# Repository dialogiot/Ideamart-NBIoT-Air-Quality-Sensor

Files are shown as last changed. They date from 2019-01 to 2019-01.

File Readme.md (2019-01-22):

##  Ideamart NB-IoT Air Quality Sensor

The board is developed based on the SIM7000C and SIM7000E Modules as well as the Microcontroller ATMega 328 based on the most popular Arduino UNO PIN layout. Therefore this board is compatible with any shield that is compatible with the Arduino UNO

* Temperature(Celsius)
* Carbon Dioxide(ppm)
* Pressure(Pa)
* Humidity(%)
* Ammonia(ppm)
* Butane(ppm)
* Carbon Monoxide(ppm)
* Ethanol(ppm)
* Hydrogen(ppm)
* Methane(ppm)
* Nitrogen Dioxide(ppm)
* Propane(ppm)
* Latitude, Longitude
* Altitude(m)
* MSL Altitude(m)
* Speed Over Ground(km/h)
* Course Over Ground(degrees)
* RSSI
* Battery Level(%)
* UTC date & Time
* Volatile Organic Compound(ppb)

More  (https://idealab.ideamart.io/EnvSensor/)

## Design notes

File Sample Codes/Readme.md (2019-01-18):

Use these sample codes for caliberation and additional sensors

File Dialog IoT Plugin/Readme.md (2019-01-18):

The air quality sensor uses CSV to send data to the platform. Therefore, the user is required to use this Java Plugin to connect the device with Dialog's IoT platform.
This plugin archive should be uploaded when onboarding the device through Dialog IoT Developer portal

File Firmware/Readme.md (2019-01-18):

Firmware for Airquality measurements
Use Arduino IDE with libraries from https://github.com/dialogiot/Dialog-NB-IOT-Hackathon/tree/master/Libraries

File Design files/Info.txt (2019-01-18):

Schematics and PCB Design files in Autodesk Eagle

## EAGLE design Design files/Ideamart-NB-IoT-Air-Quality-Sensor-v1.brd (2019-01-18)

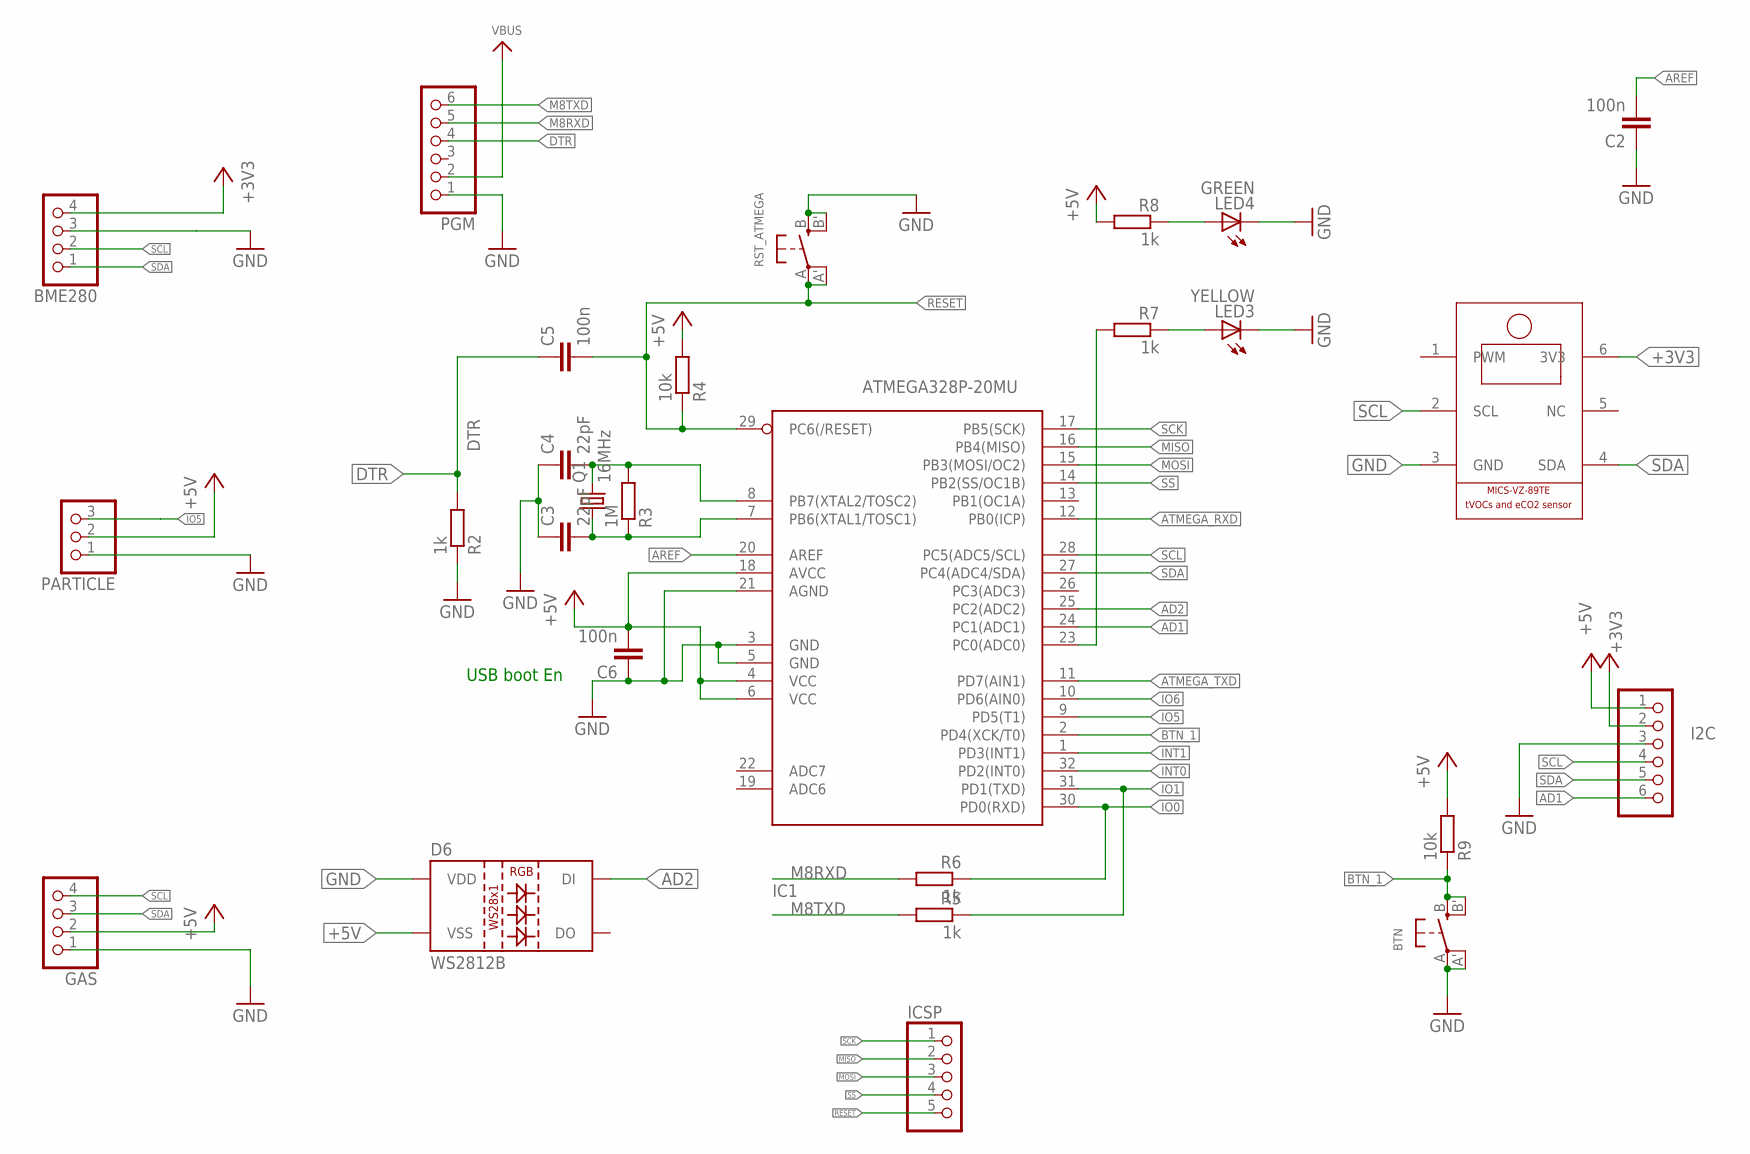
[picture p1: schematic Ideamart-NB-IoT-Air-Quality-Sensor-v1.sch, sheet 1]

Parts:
BME280: PINHD-1X4; 1X04
BTN: SWITCH_TACT_SMT4.6X2.8; BTN_KMR2_4.6X2.8
C2, C5, C6: 100n; C0805
C3, C4: 22pF; C0805
D6: WS2812B
GAS: PINHD-1X4; 1X04
I2C: PINHD-1X6; 1X06
IC1: ATMEGA328P-20MU; TQFP32-08
ICSP: PINHD-1X5; 1X05
LED3: YELLOW; CHIP-LED0805
LED4: GREEN; CHIP-LED0805
PARTICLE: PINHD-1X3; 1X03
PGM: PINHD-1X6; 1X06
Q1: 16MHz; CTS406
R2, R5, R6, R7, R8: 1k; R0805
R3: 1M; R0805
R4, R9: 10k; R0805
RST_ATMEGA: SWITCH_TACT_SMT4.6X2.8; BTN_KMR2_4.6X2.8
U$1: MICS-VZ-89TE

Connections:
+3V3: BME280.4, I2C.2, U$1.6 (3V3); also elsewhere on the board
+5V: C6.2, D6.3 (VSS), GAS.2, I2C.1, IC1.4 (VCC), IC1.6 (VCC), IC1.18 (AVCC), PARTICLE.2, R4.2, R8.2, R9.2; also elsewhere on the board
AD1: I2C.6, IC1.24 (PC1(ADC1))
AD2: D6.4 (DI), IC1.25 (PC2(ADC2))
AREF: C2.2, IC1.20 (AREF)
ATMEGA_RXD: IC1.12 (PB0(ICP)); also elsewhere on the board
ATMEGA_TXD: IC1.11 (PD7(AIN1)); also elsewhere on the board
BTN_1: BTN.B (S), BTN.B' (S1), IC1.2 (PD4(XCK/T0)), R9.1
DTR: C5.1, PGM.4, R2.2
GND: BME280.3, BTN.A, BTN.A' (P1), C2.1, C3.1, C4.1, C6.1, D6.1 (VDD), GAS.1, I2C.3, IC1.3 (GND), IC1.5 (GND), IC1.21 (AGND), LED3.C, LED4.C, PARTICLE.1, PGM.1, R2.1, RST_ATMEGA.B (S), RST_ATMEGA.B' (S1), U$1.3 (GND); also elsewhere on the board
INT0: IC1.32 (PD2(INT0))
INT1: IC1.1 (PD3(INT1))
IO0: IC1.30 (PD0(RXD)), R6.1
IO1: IC1.31 (PD1(TXD)), R5.1
IO5: IC1.9 (PD5(T1)), PARTICLE.3
IO6: IC1.10 (PD6(AIN0))
M8RXD: PGM.5, R6.2
M8TXD: PGM.6, R5.2
MISO: IC1.16 (PB4(MISO)), ICSP.2
MOSI: IC1.15 (PB3(MOSI/OC2)), ICSP.3; also elsewhere on the board
unnamed: LED3.A, R7.1
unnamed: LED4.A, R8.1
unnamed: IC1.23 (PC0(ADC0)), R7.2
RESET: C5.2, IC1.29 (PC6(/RESET)), ICSP.5, R4.1, RST_ATMEGA.A, RST_ATMEGA.A' (P1)
SCK: IC1.17 (PB5(SCK)), ICSP.1; also elsewhere on the board
SCL: BME280.2, GAS.4, I2C.4, IC1.28 (PC5(ADC5/SCL)), U$1.2 (SCL)
SDA: BME280.1, GAS.3, I2C.5, IC1.27 (PC4(ADC4/SDA)), U$1.4 (SDA)
SS: IC1.14 (PB2(SS/OC1B)), ICSP.4
VBUS: PGM.2; also elsewhere on the board
XTAL1: C3.2, IC1.7 (PB6(XTAL1/TOSC1)), Q1.1, R3.1
XTAL2: C4.2, IC1.8 (PB7(XTAL2/TOSC2)), Q1.3 (2), R3.2

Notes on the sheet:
USB boot En

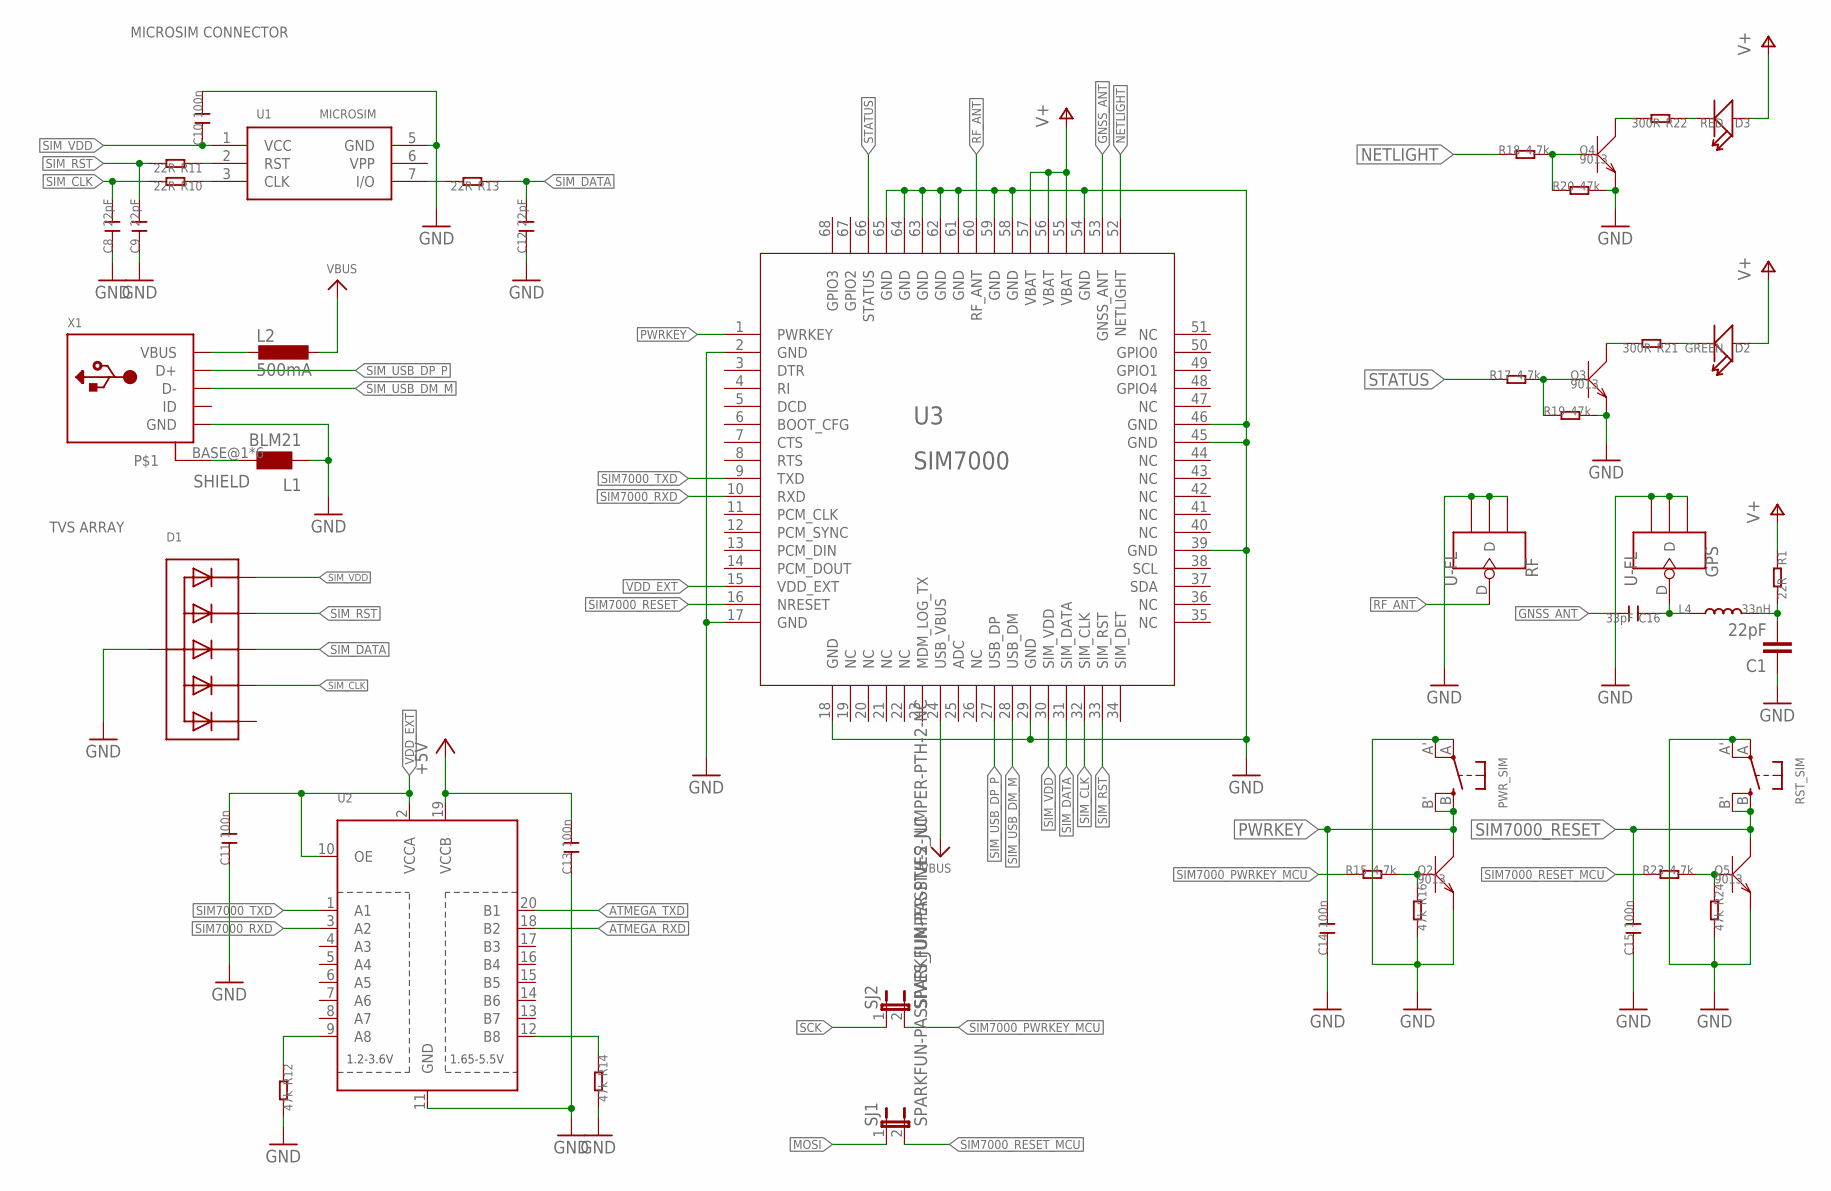
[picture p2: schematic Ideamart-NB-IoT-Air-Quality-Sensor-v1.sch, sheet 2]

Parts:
C1: 22pF; C0805
C8, C9, C12: 22pF; 0805
C10, C11, C13, C14, C15: 100n; 0805
C16: 33pF; 0805
D1: TVSARRAY_5LANE; SOT363
D2: GREEN; LED-0805
D3: RED; LED-0805
GPS: U-FL; 4P-U-FL
L1: BLM21; 0805
L2: 500mA; L1812
L4: 33nH; L0805
PWR_SIM: SWITCH_TACT_SMT4.6X2.8; BTN_KMR2_4.6X2.8
Q2, Q3, Q4, Q5: 9013; SOT23
R1, R10, R11, R13: 22R; 0805
R12, R14, R16, R19, R20, R24: 47k; 0805
R15, R17, R18, R23: 4.7k; 0805
R21, R22: 300R; 0805
RF: U-FL; 4P-U-FL
RST_SIM: SWITCH_TACT_SMT4.6X2.8; BTN_KMR2_4.6X2.8
SJ1, SJ2: SPARKFUN-PASSIVES_JUMPER-PTH-2-NC; SPARKFUN-PASSIVES_PTH-JUMPER-NC_BOTTOM_NO_SILK
U1: MICROSIM
U2: TXB0108PWR; TSSOP20
U3: SIM7000
X1: USB_MICRO_20329_V2; 4UCONN_20329_V2

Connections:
+5V: C13.2, U2.19 (VCCB); also elsewhere on the board
ATMEGA_RXD: U2.18 (B2); also elsewhere on the board
ATMEGA_TXD: U2.20 (B1); also elsewhere on the board
GND: C1.1, C8.1, C9.1, C10.2, C11.1, C12.1, C13.1, C14.1, C15.1, D1.2 (A), GPS.GND1, GPS.GND2, GPS.GND3, L1.1, PWR_SIM.A, PWR_SIM.A' (P1), Q2.2 (E), Q3.2 (E), Q4.2 (E), Q5.2 (E), R12.2, R14.2, R16.2, R19.2, R20.2, R24.2, RF.GND1, RF.GND2, RF.GND3, RST_SIM.A, RST_SIM.A' (P1), U1.5 (GND), U2.11 (GND), U3.2 (GND), U3.17 (GND), U3.18 (GND), U3.29 (GND), U3.39 (GND), U3.45 (GND), U3.46 (GND), U3.54 (GND), U3.58 (GND), U3.59 (GND), U3.61 (GND), U3.62 (GND), U3.63 (GND), U3.64 (GND), U3.65 (GND), X1.GND; also elsewhere on the board
GNSS_ANT: C16.2, U3.53 (GNSS_ANT)
GPIO2: U3.67 (GPIO2)
GPIO3: U3.68 (GPIO3)
MOSI: SJ1.1; also elsewhere on the board
unnamed: Q3.3 (C), R21.2
unnamed: D2.-, R21.1
unnamed: Q3.1 (B), R17.2, R19.1
unnamed: R13.2, U1.7 (I/O)
unnamed: R10.1, U1.3 (CLK)
unnamed: R11.1, U1.2 (RST)
unnamed: Q5.1 (B), R23.2, R24.1
unnamed: L2.2, X1.VBUS
unnamed: Q4.3 (C), R22.2
unnamed: D3.-, R22.1
unnamed: Q4.1 (B), R18.2, R20.1
unnamed: C16.1, GPS.D, L4.1
unnamed: R12.1, U2.9 (A8)
unnamed: R14.1, U2.12 (B8)
unnamed: C1.2, L4.2, R1.2
unnamed: Q2.1 (B), R15.2, R16.1
NETLIGHT: R18.1, U3.52 (NETLIGHT)
PWRKEY: C14.2, PWR_SIM.B (S), PWR_SIM.B' (S1), Q2.3 (C), U3.1 (PWRKEY)
RF_ANT: RF.D, U3.60 (RF_ANT)
SCK: SJ2.1; also elsewhere on the board
SHIELD: L1.2, X1.BASE@1, X1.BASE@2, X1.SPRT@1, X1.SPRT@2, X1.SPRT@3, X1.SPRT@4
SIM7000_PWRKEY_MCU: R15.1, SJ2.2
SIM7000_RESET: C15.2, Q5.3 (C), RST_SIM.B (S), RST_SIM.B' (S1), U3.16 (NRESET)
SIM7000_RESET_MCU: R23.1, SJ1.2
SIM7000_RXD: U2.3 (A2), U3.10 (RXD)
SIM7000_TXD: U2.1 (A1), U3.9 (TXD)
SIM_CLK: C8.2, D1.5 (C4), R10.2, U3.32 (SIM_CLK)
SIM_DATA: C12.2, D1.4 (C3), R13.1, U3.31 (SIM_DATA)
SIM_RST: C9.2, D1.3 (C2), R11.2, U3.33 (SIM_RST)
SIM_USB_DM_M: U3.28 (USB_DM), X1.D-
SIM_USB_DP_P: U3.27 (USB_DP), X1.D+
SIM_VDD: C10.1, D1.1 (C1), U1.1 (VCC), U3.30 (SIM_VDD)
STATUS: R17.1, U3.66 (STATUS)
V+: D2.+, D3.+, R1.1, U3.55 (VBAT), U3.56 (VBAT), U3.57 (VBAT); also elsewhere on the board
VBUS: L2.1, U3.24 (USB_VBUS); also elsewhere on the board
VDD_EXT: C11.2, U2.2 (VCCA), U2.10 (OE), U3.15 (VDD_EXT)

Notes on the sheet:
TVS ARRAY
MICROSIM CONNECTOR

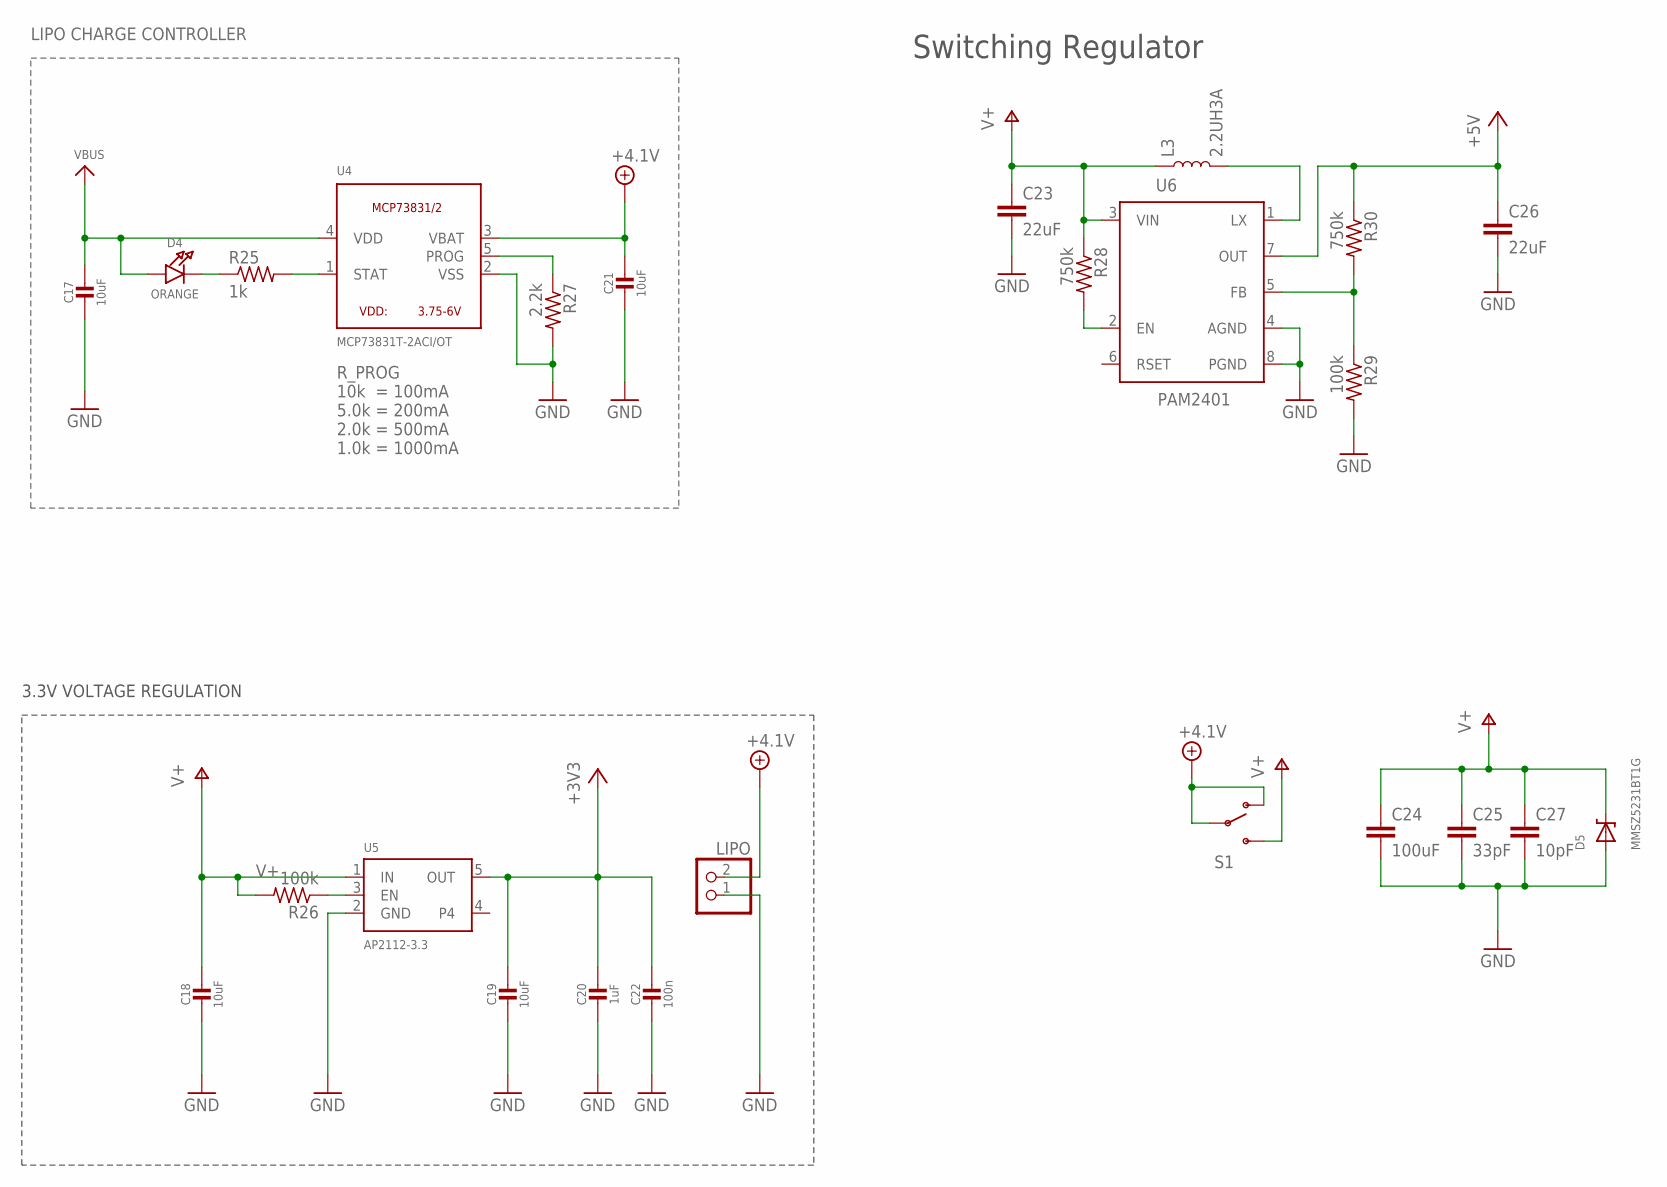
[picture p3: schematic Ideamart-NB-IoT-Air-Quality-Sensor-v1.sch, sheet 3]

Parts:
C17, C21: 10uF; _0805
C18, C19: 10uF; _0805MP
C20: 1uF; _0805MP
C22: 100n; _0805MP
C23, C26: 22uF; 0805
C24: 100uF; 1210
C25: 33pF; 0805
C27: 10pF; 0805
D4: ORANGE; CHIPLED_0805
D5: MMSZ5231BT1G; SOD-123
L3: 2.2UH3A; INDUCTOR_4X4MM
LIPO: JST_2PIN-SMT; JST-PH-2-SMT
R25: 1k; M0805
R26, R29: 100k; M0805
R27: 2.2k; M0805
R28, R30: 750k; M0805
S1: SWITCH-SPDT-SMD-A; SWITCH-SPST-SMD-A
U4: MCP73831T-2ACI/OT; SOT23-5
U5: AP2112-3.3; SOT23-5
U6: PAM2401; MSOP8

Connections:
+3V3: C19.1, C20.1, C22.1, U5.5 (OUT); also elsewhere on the board
+4.1V: C21.1, LIPO.2 (1), S1.1 (O), S1.2, U4.3 (VBAT)
+5V: C26.1, R30.1, U6.7 (OUT); also elsewhere on the board
EN: R28.2, U6.2 (EN)
GND: C17.2, C18.2, C19.2, C20.2, C21.2, C22.2, C23.2, C24.2, C25.2, C26.2, C27.2, D5.A, LIPO.1 (2), R27.2, R29.2, U4.2 (VSS), U5.2 (GND), U6.4 (AGND), U6.8 (PGND); also elsewhere on the board
unnamed: R26.1, U5.3 (EN)
unnamed: D4.C, R25.1
unnamed: R25.2, U4.1 (STAT)
unnamed: R27.1, U4.5 (PROG)
unnamed: R29.1, R30.2, U6.5 (FB)
unnamed: L3.P$2 (2), U6.1 (LX)
V+: C18.1, C23.1, C24.1, C25.1, C27.1, D5.C, L3.P$1 (1), R26.2, R28.1, S1.3 (S), U5.1 (IN), U6.3 (VIN); also elsewhere on the board
VBUS: C17.1, D4.A, U4.4 (VDD); also elsewhere on the board

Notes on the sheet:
3.3V VOLTAGE REGULATION
R_PROG 10k = 100mA 5.0k = 200mA 2.0k = 500mA 1.0k = 1000mA
LIPO CHARGE CONTROLLER
Switching Regulator

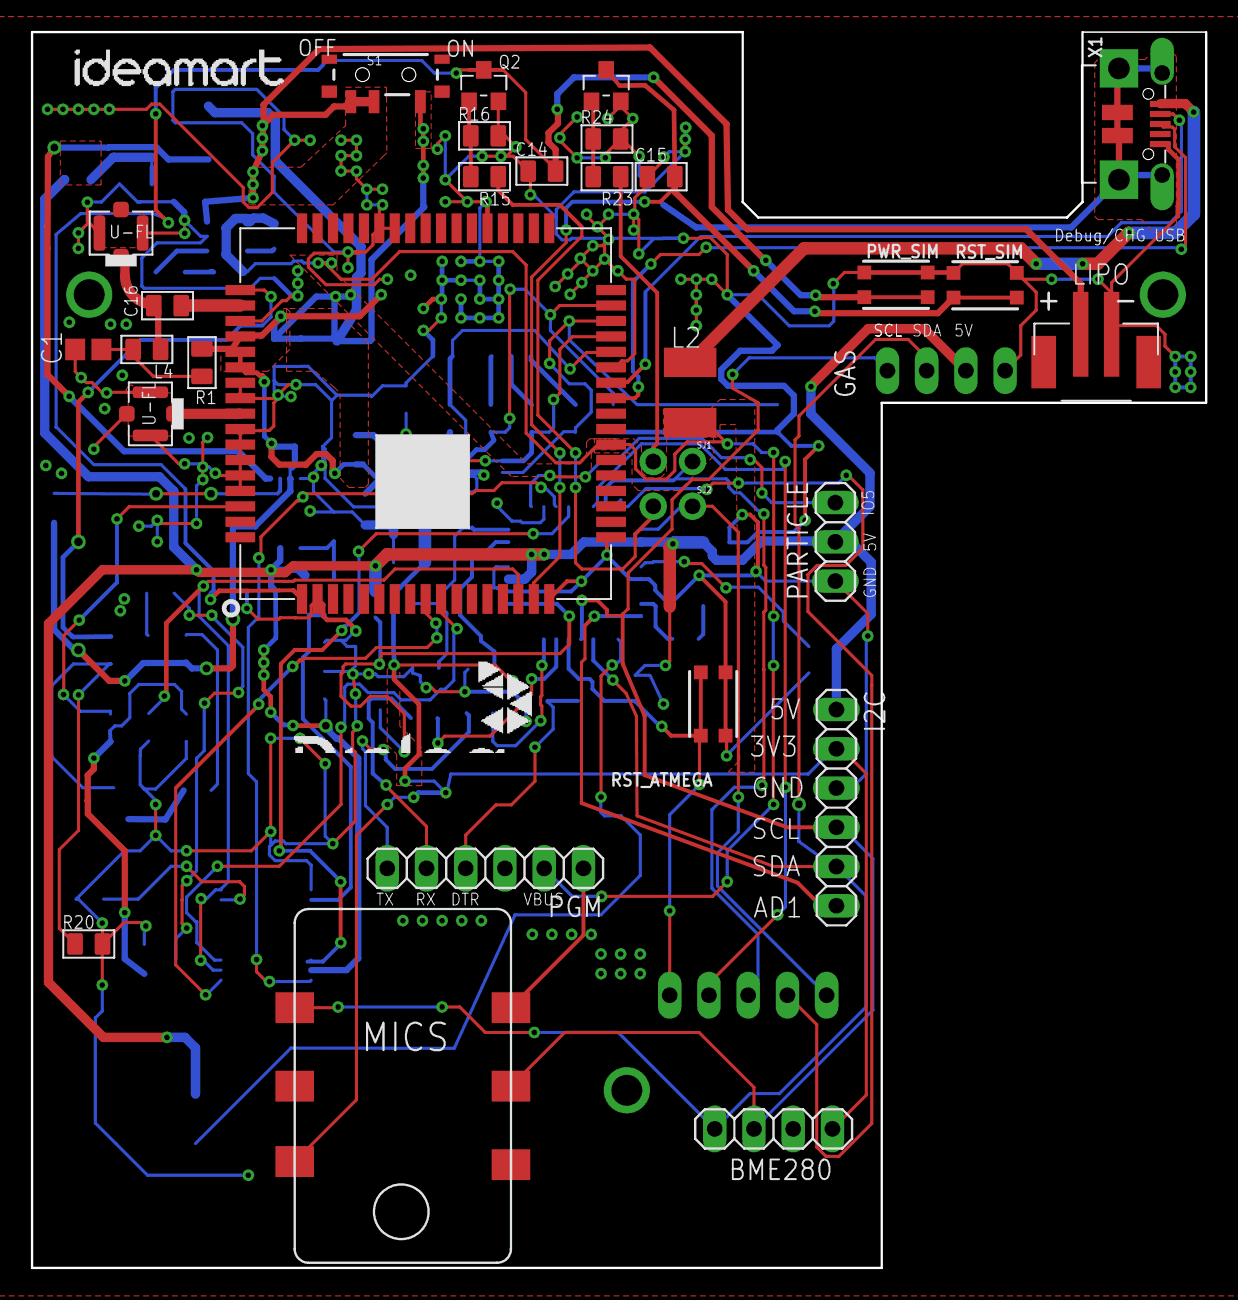
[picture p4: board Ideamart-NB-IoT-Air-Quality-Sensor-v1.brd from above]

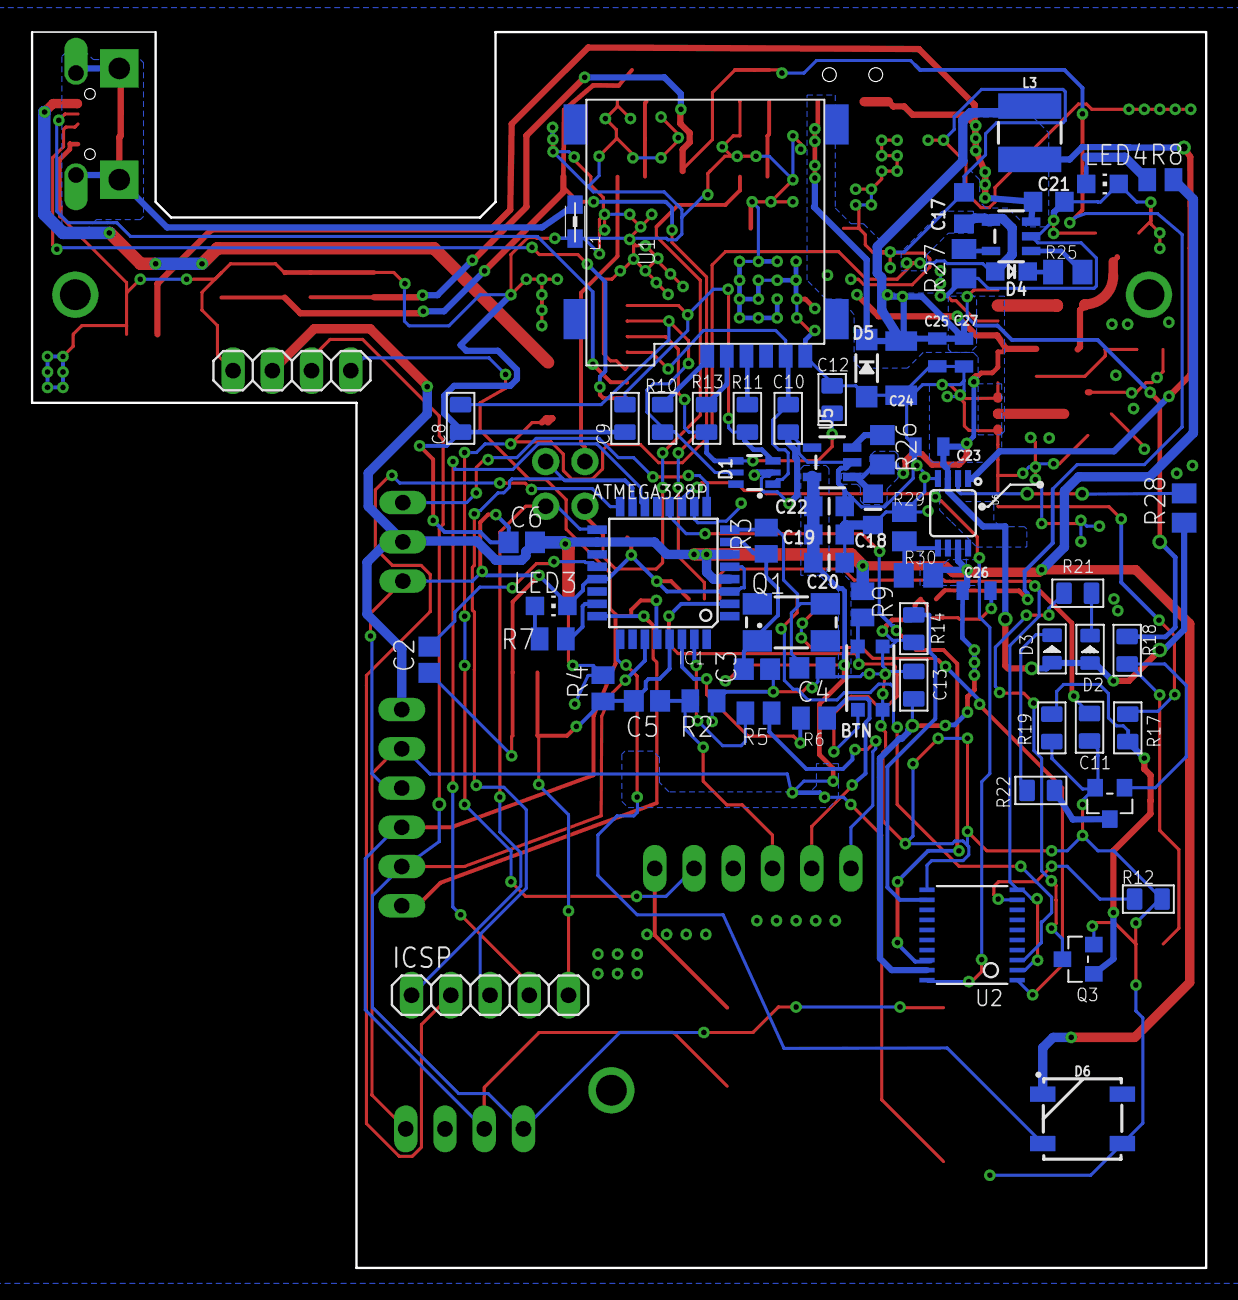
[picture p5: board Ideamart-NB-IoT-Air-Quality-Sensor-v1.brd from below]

Board: 2 copper layers, 76.0 x 80.0 mm, 98 parts (68 on the bottom side), 71 nets.

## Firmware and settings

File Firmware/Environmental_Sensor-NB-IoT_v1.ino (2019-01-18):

#define TINY_GSM_MODEM_SIM808
#include <TinyGsmClient.h>
#include <PubSubClient.h>
#include <SoftwareSerial.h>

#include <Wire.h>
#include "MutichannelGasSensor.h"
#include <BME280.h>
#include <Adafruit_NeoPixel.h>  
#include "MICS-VZ-89TE.h"

//ideaBoard pin configuration
#define ideaBoard_PWRKEY 13
#define ideaBoard_RX      8
#define ideaBoard_TX      7
#define ideaBoard_RST    11

#define PIN              A2      // LED on analog pin 2
#define NUMLEDS           1      // Use total of 1 LED

MICS_VZ_89TE mics;
BME280 bme;
Adafruit_NeoPixel leds = Adafruit_NeoPixel(NUMLEDS, PIN, NEO_GRB + NEO_KHZ800);

SoftwareSerial SerialAT(7,8); // RX, TX

TinyGsm modem(SerialAT);
TinyGsmClient client(modem);
PubSubClient mqtt(client);

unsigned long pr = 0;        // will store last time published
const long interval = 50000;           // interval at which to publish data (milliseconds)
#define gps 2   // 0 - disable, 1- send periodically, 2 - send only at powerup/reset

//Dialog IoT params
#define ID "env123"
#define PUB_TOPIC "ideamart/environmentalsensor/v3/common"


void setup() {
  pinMode(ideaBoard_RST, OUTPUT);
  digitalWrite(ideaBoard_RST, LOW);

  pinMode(ideaBoard_PWRKEY, OUTPUT);
  //digitalWrite(ideaBoard_PWRKEY, LOW);
  //delay(200);

  digitalWrite(ideaBoard_PWRKEY, HIGH);
  //delay(180);
  //digitalWrite(ideaBoard_PWRKEY, LOW);
    
  Serial.begin(115200);
  bme.begin();
  mics.begin();
  gas.begin(0x04);//the default I2C address of the slave is 0x04
  gas.powerOn();
  
  SerialAT.begin(4800);
  leds.begin();  
  leds.setPixelColor(0, leds.Color(50, 0, 0));
  leds.show();                      
  delay(500);

  Serial.print(F("Network  : "));
  if (!modem.waitForNetwork()) {
    Serial.println(F(" fail"));
    while (true);
  }
  Serial.println(F(" OK"));
  Serial.print(F("GPRS     : "));
  if (!modem.gprsConnect("dialogbb", "", "")) {
    Serial.println(F(" fail"));
    while (true);
    rgb(3,1,0,0);

  }
  Serial.println(F(" OK"));
  // MQTT Broker setup
  mqtt.setServer("mqtt.iot.ideamart.io", 1883);
  if(gps == 2){
  mCon();
  gpsPush();}
//
//  Serial.println(modem.getSimCCID());
//    Serial.println(modem.getIMEI());
//      Serial.println(modem.getOperator());
//        Serial.println(modem.localIP());
}

void loop() {

    unsigned long cr = millis();

  if (cr - pr >= interval) {
    pr = cr;

  if (mCon()) {    
    DataPush();
    if(gps == 1){
      gpsPush();
    }
    rgb(3,5,1,0);
    rgb(3,5,1,0);
  }
 mqtt.disconnect();
  } 
  rgb(5,0,1,0);
}


boolean mCon() {
  Serial.print(F("MQTT     : "));
  randomSeed(analogRead(5)); //analog pin 5 used to generate random number
  
  if (!mqtt.connect("ENV-3210","ideamart-environmentalsensor-v3_1777","1544415787_1777")) {
    Serial.println(F(" fail"));
    return false;
  }
  Serial.println(F(" OK"));
  return mqtt.connected();
}

void rgb(int wait,int r, int g, int b){
  for(int i=0; i<255; i++) {            // Loop through next color change
    leds.setPixelColor(0, leds.Color(r*i, g*i, b*i)); 
    leds.show(); 
    delay(wait); 
  }
  for(int i=255; i>=0; i--) {            // Count up color units from 0 to 255
    leds.setPixelColor(0, leds.Color(r*i, g*i, b*i));  // Color mix for LED
    leds.show();                        // Set the LED
    delay(wait);                        // Delay for visual effect
  }
  
}

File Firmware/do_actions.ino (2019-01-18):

void DataPush(){ 
  
  mics.readSensor();  
  float t= bme.readTemp();
  float p= bme.readPressure();
  float a= bme.readAltitude();
  float h= bme.readHumidity();
  float nh3   =gas.measure_NH3();   
  float h2    =gas.measure_H2(); 
  float c2h5oh=gas.measure_C2H5OH(); 
  float co2   =mics.getCO2();
  float co    =gas.measure_CO(); 
  float no2   =gas.measure_NO2(); 
  float c3h8  =gas.measure_C3H8(); 
  float c4h10 =gas.measure_C4H10();
  float ch4   =gas.measure_CH4(); 
  int sig     =modem.getSignalQuality();
  int bat     =modem.getBattPercent();
  float voc   =mics.getVOC();
  
  String csv = "data,"+ String(ID)+"," + String(t)+","+String(p)+","+String(a)+","+String(h)+","+String(nh3)+","+String(co)+","+String(no2)+","+String(c3h8)+","+String(c4h10)+","+String(ch4)+","+String(h2)+","+String(c2h5oh)+","+String(co2)+","+String(voc)+","+String(sig)+","+String(bat);

  //String csv1 = "{\"eventName\":\"data1\",\"status\":\"none\",\"t\":"+String(t)+",\"p\":"+String(p)+",\"a\":"+String(a)+",\"h\":"+String(h)+",\"nh\":"+String(nh3)+",\"h2\":"+String(h2)+",\"c2\":"+String(c2h5oh)+",\"co2\":"+String(co2)+",\"mac\":\""+ID+"\"}";
  mqtt.publish(PUB_TOPIC,csv.c_str());
  Serial.println(csv);
}


void gpsPush(){
  float lat,lon;
  if(modem.enableGPS()){
  Serial.print("Locating");

  int count = 0;
  while(!modem.getGPS(&lat,&lon)){
    count++;
     Serial.print(F("."));
     if(count == 300){  // retry attempts for gps
      Serial.println(F("GPS failed..Check antenna"));  // if gps error,check gps antenna 
      break;
     }
  }
  if(count < 300){
      Serial.println();
      Serial.print(F("GPS Location: "));
      Serial.println(String(lat)+","+String(lon));

      mqtt.publish(PUB_TOPIC,("gps," + String(ID) + "," + modem.getGPSraw()).c_str());
  }
      modem.disableGPS();
  }
  else(F("GPS failed.."));
}

void other(){
  
}

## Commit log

2019-01-18 Add files via upload
    Eagle design files for Air quality sensor version 1
    [Ideamart-NB-IoT-Air-Quality-Sensor-v1.brd, Ideamart-NB-IoT-Air-Quality-Sensor-v1.sch]
2019-01-18 Add files via upload
    Arduino code for Air quality measurements

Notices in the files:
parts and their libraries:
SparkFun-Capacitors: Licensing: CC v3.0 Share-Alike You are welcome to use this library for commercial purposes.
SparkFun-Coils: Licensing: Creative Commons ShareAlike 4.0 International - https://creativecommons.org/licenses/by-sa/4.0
